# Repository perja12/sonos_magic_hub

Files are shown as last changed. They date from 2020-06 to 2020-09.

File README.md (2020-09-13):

# Sonos Magic Hub

_UPDATE 2020-09-13:_ This workaround isn't needed anymore! Go to "device connector" in the menus of the LG TV and setup a new soundbar. When you come to the manufacturer selection you won't see Sonos listed, but if you use the search box and search for Sonos it will show up (I'm pretty sure it wasn't there before!). Now you should be able to control the Sonos Playbar with the remote when the TV is on.

Next step is to open the Sonos app (S1), go to the settings for the Playbar and follow the instructions for setting up a remote ("Remote Control Setup"). And voilà: you can now control the Playbar with the MagicRemote with TV both on and off.

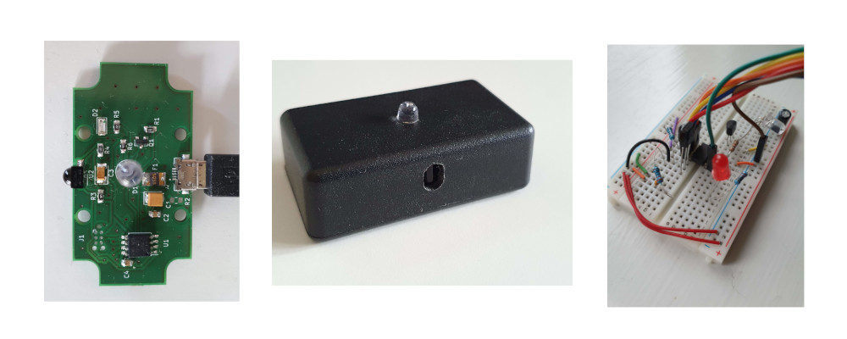
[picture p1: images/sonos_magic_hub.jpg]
Project pictures


This project contains firmware and hardware design files for using the LG Magic Remote that comes with LG OLED C9 TV with a Sonos Playbar. Sonos Playbar already has support for universal remotes, but the LG Magic Remote sends one set of codes when the TV is on and another set when the TV is off. So controlling the volume up, down and mute works fine when the TV is on, but not when it is off. It's not clear why LG has done it this way, but probably it is for controlling other LG devices.

Instead of waiting for LG to fix this I created a small circuit to translate the IR codes.

Note: there are various forum posts about the reverse problem for LG OLED CX. Apparently the Sonos Playbar can only be controlled by the LG remote when TV is off. This project doesn't solve that.

## How does it work?

This is straightforward: when a IR signal is received it will be converted to a code that the Sonos Playbar understands.

## List of IR codes

The table shows the IR codes sent by the remote when it is configured to send Philips RC6 codes as described here: https://support.sonos.com/s/article/3479?language=en

| Command | IR code (TV off) | IR code (TV on) |
|---|---|---|
| Volume up | NEC, 20DF40BF, 32 bits | RC6, 1010, 20 bits |
| Volume down | NEC, 20DFC03F, 32 bits | RC6, 1011, 20 bits |
| Mute | NEC, 0DF906F, 32 bits | RC6, 100D, 20 bits |

## How to build the firmware

Use the Arduino IDE and install the ATTinyCore (https://github.com/SpenceKonde/ATTinyCore). Do this from Boards Manager in the IDE. Select "ATtiny 25/45/85" under boards and clock to 8 MHz (internal). For uploading the firmware I have used USBasp with Tag-Connect, but you can you use any way you prefer. Remember to burn the bootloader before uploading the firmware.

## Various notes

* Use this at your own risk! In the firmware I included support for NEC repeat code that the remote sends if one of the buttons are held down. There is a limit of 5 repeats in a row to avoid ramping up the volume too fast.
* There is no USB enumeration and thereby it is not according to the USB specifications. Still I think it should work fine with most USB hosts.
* It was unclear if the shield of the USB connector should be connected to GND or not. That is why I included R2. I left it unpopulated.
* The fuse (F1) is probably not needed. Maybe it should have some TVS diodes instead to suppress ESD.
* The IR library is from https://gist.github.com/SeeJayDee/caa9b5cc29246df44e45b8e7d1b1cdc5

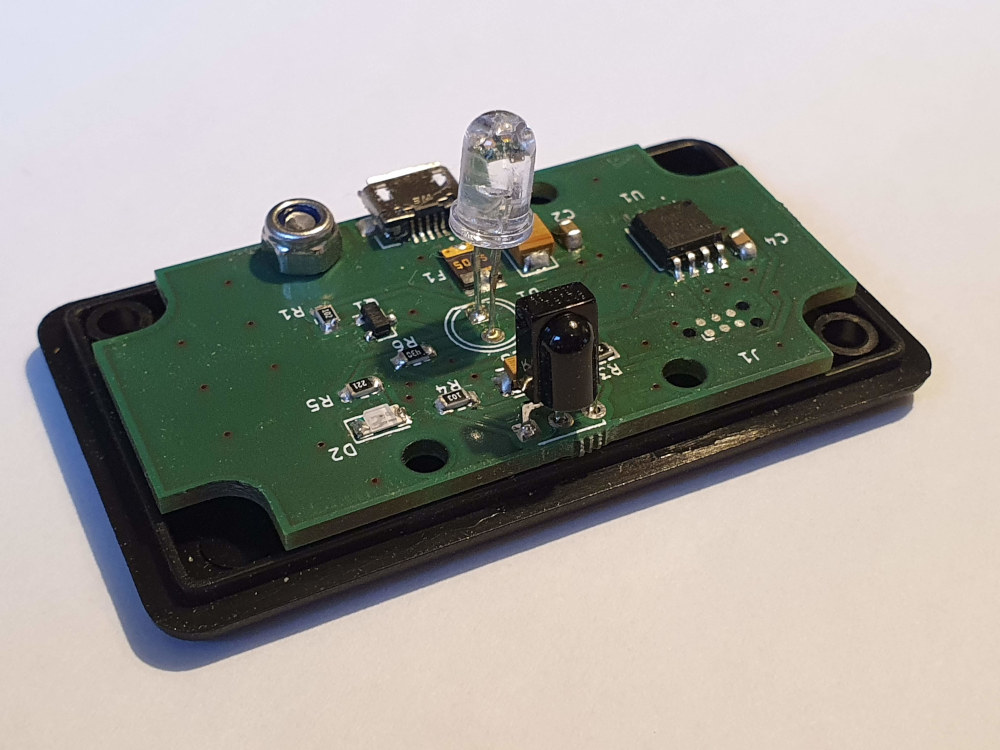
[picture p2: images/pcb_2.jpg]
PCB


## BOM

|Ref|Value |Footprint |
|---|---|---|
|C1 |10 uF |Capacitor_Tantalum_SMD:CP_EIA-3528-12_Kemet-T_Pad1.50x2.35mm_HandSolder |
|C2 |1 uF |Capacitor_SMD:C_0805_2012Metric_Pad1.15x1.40mm_HandSolder |
|C3 |0.1 uF |Capacitor_Tantalum_SMD:CP_EIA-3528-12_Kemet-T_Pad1.50x2.35mm_HandSolder |
|C4 |0.1 uF |Capacitor_SMD:C_0805_2012Metric_Pad1.15x1.40mm_HandSolder |
|D1 |LD271 |LED_THT:LED_D5.0mm_IRGrey |
|D2 |LED |LED_SMD:LED_1206_3216Metric |
|F1 |Polyfuse_Small|FUSM1812X02:FUSM1812X02 |
|J1 |AVR-ISP-6 |(No actual part) Connector:Tag-Connect_TC2030-IDC-NL_2x03_P1.27mm_Vertical|
|J2 |629105136821  |(Micro USB connector) WE_629105136821:WE_629105136821 |
|Q1 |MMBT3904 |Package_TO_SOT_SMD:SOT-23 |
|R1 |1K |Resistor_SMD:R_0805_2012Metric_Pad1.15x1.40mm_HandSolder |
|R2 |0 |Resistor_SMD:R_0805_2012Metric_Pad1.15x1.40mm_HandSolder |
|R3 |220 |Resistor_SMD:R_0805_2012Metric_Pad1.15x1.40mm_HandSolder |
|R4 |10K |Resistor_SMD:R_0805_2012Metric_Pad1.15x1.40mm_HandSolder |
|R5 |220 |Resistor_SMD:R_0805_2012Metric_Pad1.15x1.40mm_HandSolder |
|R6 |35 |Resistor_SMD:R_0805_2012Metric_Pad1.15x1.40mm_HandSolder |
|U1 |ATtiny85V-10SU|Package_SO:SOIJ-8_5.3x5.3mm_P1.27mm |
|U2 |TSOP38238 |OptoDevice:Vishay_MINICAST-3Pin |

The PCB fits inside the Hammond 1551H (http://www.hammondmfg.com/pdf/1551H.pdf).

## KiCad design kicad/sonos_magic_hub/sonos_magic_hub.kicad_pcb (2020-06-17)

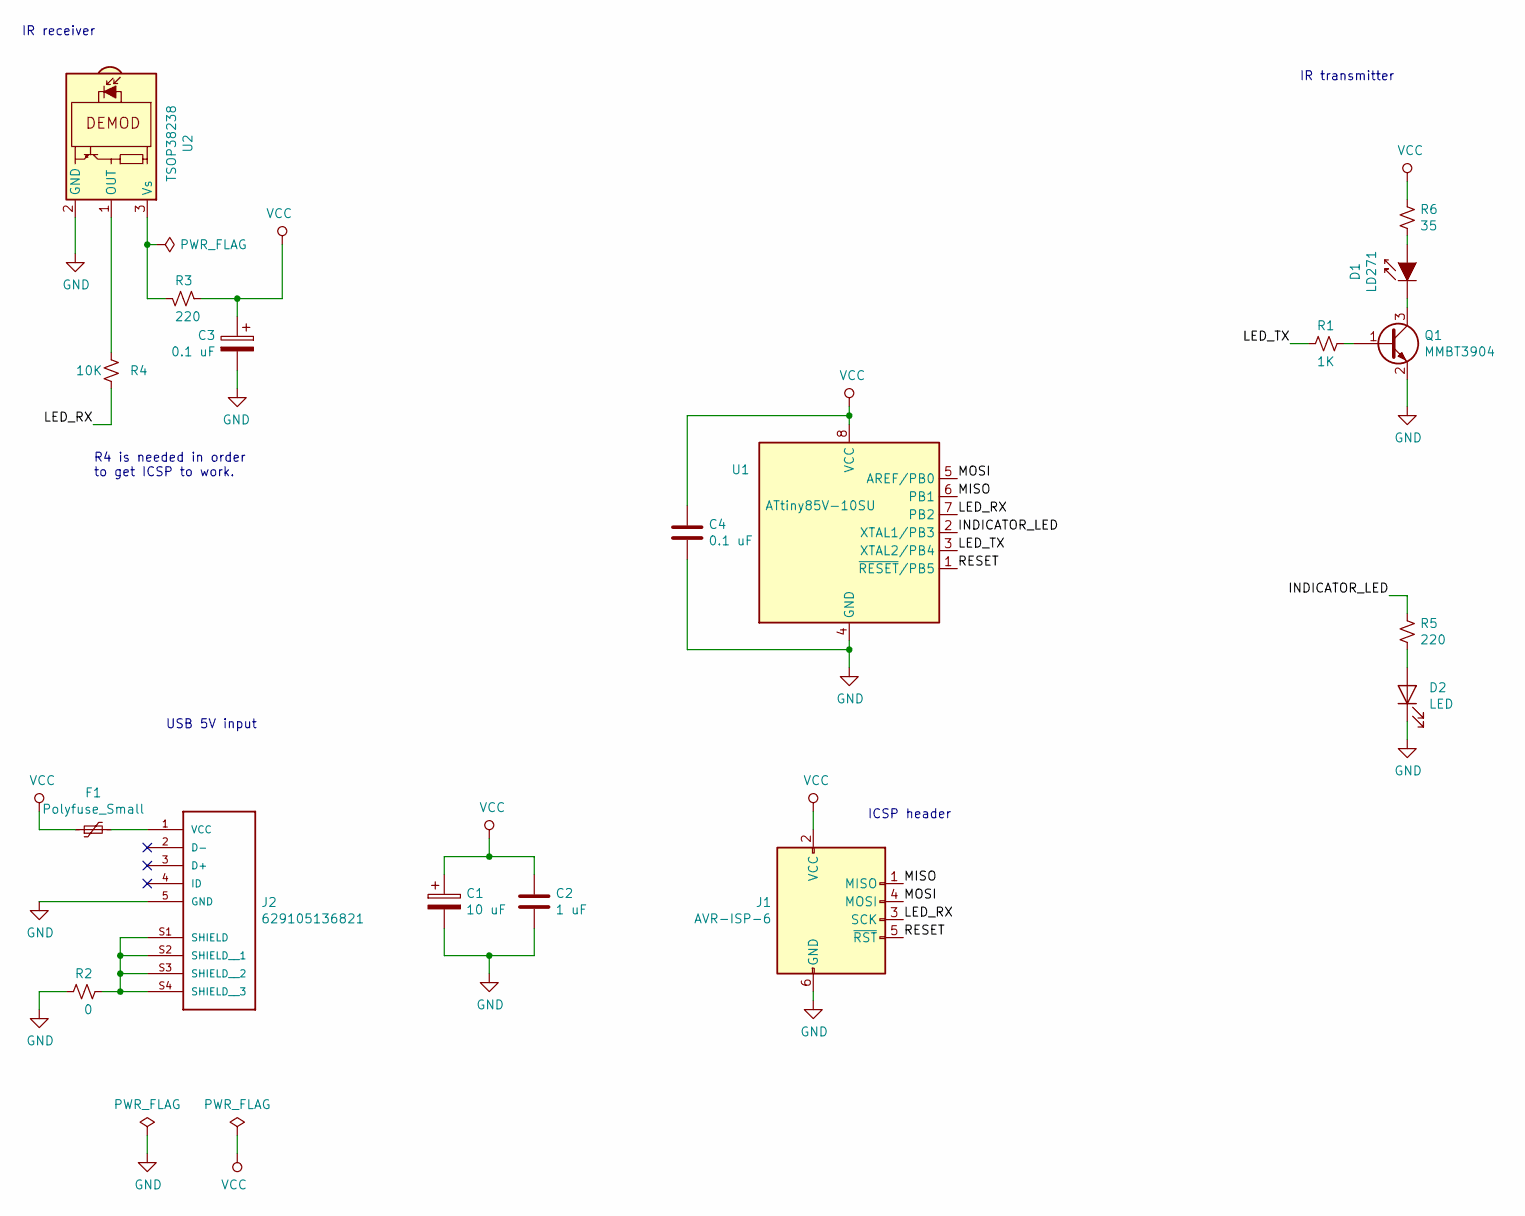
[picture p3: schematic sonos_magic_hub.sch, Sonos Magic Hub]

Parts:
C1: 10 uF; CP_EIA-3528-12_Kemet-T_Pad1.50x2.35mm_HandSolder
C2: 1 uF; C_0805_2012Metric_Pad1.15x1.40mm_HandSolder
C3: 0.1 uF; CP_EIA-3528-12_Kemet-T_Pad1.50x2.35mm_HandSolder
C4: 0.1 uF; C_0805_2012Metric_Pad1.15x1.40mm_HandSolder
D1: LD271; LED_D5.0mm_IRGrey
D2: LED; LED_1206_3216Metric
F1: Polyfuse_Small; FUSM1812X02
J1: AVR-ISP-6; Tag-Connect_TC2030-IDC-NL_2x03_P1.27mm_Vertical
J2: 629105136821; WE_629105136821
Q1: MMBT3904; SOT-23
R1: 1K; R_0805_2012Metric_Pad1.15x1.40mm_HandSolder
R2: 0; R_0805_2012Metric_Pad1.15x1.40mm_HandSolder
R3, R5: 220; R_0805_2012Metric_Pad1.15x1.40mm_HandSolder
R4: 10K; R_0805_2012Metric_Pad1.15x1.40mm_HandSolder
R6: 35; R_0805_2012Metric_Pad1.15x1.40mm_HandSolder
U1: ATtiny85V-10SU; SOIJ-8_5.3x5.3mm_P1.27mm
U2: TSOP38238; Vishay_MINICAST-3Pin

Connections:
/INDICATOR_LED: R5.1, U1.2 (XTAL1/PB3)
/LED_RX: J1.3 (SCK), R4.2, U1.7 (PB2)
/LED_TX: R1.1, U1.3 (XTAL2/PB4)
/MISO: J1.1 (MISO), U1.6 (PB1)
/MOSI: J1.4 (MOSI), U1.5 (AREF/PB0)
/RESET: J1.5 (~RST), U1.1 (~RESET~/PB5)
GND: C1.2, C2.2, C3.2, C4.2, D2.1 (K), J1.6 (GND), J2.5 (GND), Q1.2 (E), R2.1, U1.4 (GND), U2.2 (GND)
unnamed: D1.1 (K), Q1.3 (C)
unnamed: D1.2 (A), R6.2
unnamed: D2.2 (A), R5.2
unnamed: F1.2, J2.1 (VCC)
unnamed: J2.S1 (SHIELD), J2.S2 (SHIELD__1), J2.S3 (SHIELD__2), J2.S4 (SHIELD__3), R2.2
unnamed: Q1.1 (B), R1.2
unnamed: R3.2, U2.3 (Vs)
unnamed: R4.1, U2.1 (OUT)
VCC: C1.1, C2.1, C3.1, C4.1, F1.1, J1.2 (VCC), R3.1, R6.1, U1.8 (VCC)

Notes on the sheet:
ICSP header
IR receiver
IR transmitter
USB 5V input
R4 is needed in order to get ICSP to work.

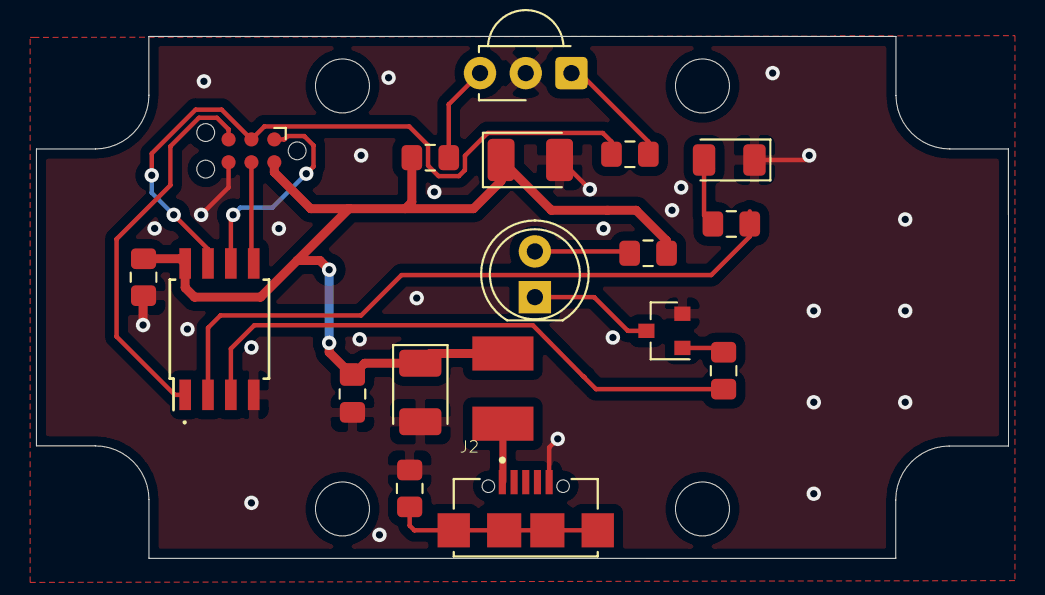
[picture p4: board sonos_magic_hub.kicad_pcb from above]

Board: 2 copper layers, 54.0 x 29.0 mm, 18 parts (0 on the bottom side), 16 nets.

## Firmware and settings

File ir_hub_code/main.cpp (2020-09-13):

#include <Arduino.h>
#include <avr/interrupt.h>
#include <avr/power.h>
#include <avr/sleep.h>
#include <util/delay.h>

#include "tiny_IRremote.h"

#define IR_RECV_PIN 2
#define INDICATOR_PIN 3

const uint32_t NEC_VOLUME_UP   = 0x20DF40BF;
const uint32_t NEC_VOLUME_DOWN = 0x20DFC03F;
const uint32_t NEC_VOLUME_MUTE = 0x20DF906F;
const uint32_t NEC_REPEAT      = 0xFFFFFFFF;

const uint16_t RC6_VOLUME_UP   = 0x1010;
const uint16_t RC6_VOLUME_DOWN = 0x1011;
const uint16_t RC6_VOLUME_MUTE = 0x100D;

// Limit the number of repeats to avoid damaging speaker element.
const uint8_t MAX_REPEATS = 5;

IRsend irsend;
IRrecv irrecv(IR_RECV_PIN);

uint32_t last_code = 0;
uint8_t num_repeats = 0;

EMPTY_INTERRUPT(PCINT0_vect);

void blink(uint8_t num) {
  for (uint8_t i = 0; i < num; i++) {
    PORTB |= (1 << INDICATOR_PIN);
    _delay_ms(20);
    PORTB &= ~(1 << INDICATOR_PIN);
    _delay_ms(20);
  }
}

void setup() {
  // The internal oscillator seems to be pretty accurate from factory for ATTiny85V.
  // Test sketch that generates 10 kHz PWM measures approx 10.07 kHz with
  // OSCCAL -= 1.
  OSCCAL -= 1;

  set_sleep_mode(SLEEP_MODE_IDLE);
  irrecv.enableIRIn();

  // Turn off ADC and USI to save power.
  ADCSRA &= ~ bit(ADEN);
  power_adc_disable();
  power_usi_disable();

  // Configure DDB0 and DDB1 as output to save power (unused).
  // In addition PB4 is configured by tiny_IRremote.
  DDRB = (1 << INDICATOR_PIN) | (1 << DDB0) | (1 << DDB1);

  PCMSK  |= _BV (PCINT2);  // enable pin change interrupt for PCINT2 pin (IR_RECV_PIN)
  GIFR   |= bit (PCIF);    // clear any outstanding interrupts
  GIMSK  |= bit (PCIE);    // enable pin change interrupts

  blink(3);
}

void send(uint32_t code) {
  irsend.sendRC6(code, 20);
  last_code = code;
  num_repeats = 0;
}

void send_last_code() {
  if (num_repeats < MAX_REPEATS) {
    irsend.sendRC6(last_code, 20);
    num_repeats++;
    _delay_ms(50);
  }
}

void loop() {
  decode_results results;
  uint8_t found_code = 0;

  // The IR library uses timer1 to collect raw IR data.
  // This is done in chunks of 50 ms. Repeatedly check for
  // data until there is data to decode or there is a timeout.
  uint32_t decode_start = millis();
  while ((found_code = irrecv.decode(&results)) == 0) {
    if ((millis() - decode_start) > 100) {
      break;
    }
  }

  if (found_code) {
    if (results.decode_type == NEC) {
      blink(1);
      switch(results.value) {
        case NEC_VOLUME_UP: send(RC6_VOLUME_UP); break;
        case NEC_VOLUME_DOWN: send(RC6_VOLUME_DOWN); break;
        case NEC_VOLUME_MUTE: send(RC6_VOLUME_MUTE); break;
        case NEC_REPEAT: send_last_code(); break;
      }
    }
    irrecv.enableIRIn();
    irrecv.resume();
  }

  power_timer0_disable();
  power_timer1_disable();
  sleep_mode();
  power_timer0_enable();
  power_timer1_enable();
}

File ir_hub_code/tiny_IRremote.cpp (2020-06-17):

/*
 * tiny_IRremote
 * Version 0.2 July, 2016
 * Christian D'Abrera
 * Fixed what was originally rather broken code from http://www.gammon.com.au/Arduino/
 * ...itself based on work by Ken Shirriffr.
 *
 * This code was tested for both sending and receiving IR on an ATtiny85 DIP-8 chip.
 * IMPORTANT: IRsend only works from PB4 ("pin 4" according to Arduino). You will need to 
 * determine which physical pin this corresponds to for your chip, and connect your transmitter
 * LED there.
 *
 * Copyright 2009 Ken Shirriff
 * For details, see http://arcfn.com/2009/08/multi-protocol-infrared-remote-library.html
 *
 * Interrupt code based on NECIRrcv by Joe Knapp
 * http://www.arduino.cc/cgi-bin/yabb2/YaBB.pl?num=1210243556
 * Also influenced by http://zovirl.com/2008/11/12/building-a-universal-remote-with-an-arduino/
 */

#include "tiny_IRremote.h"
#include "tiny_IRremoteInt.h"

// Provides ISR
#include <avr/interrupt.h>

volatile irparams_t irparams;

// These versions of MATCH, MATCH_MARK, and MATCH_SPACE are only for debugging.
// To use them, set DEBUG in tiny_IRremoteInt.h
// Normally macros are used for efficiency
#ifdef DEBUG
#error debug enabled
int MATCH(int measured, int desired) {
  Serial.print("Testing: ");
  Serial.print(TICKS_LOW(desired), DEC);
  Serial.print(" <= ");
  Serial.print(measured, DEC);
  Serial.print(" <= ");
  Serial.println(TICKS_HIGH(desired), DEC);
  return measured >= TICKS_LOW(desired) && measured <= TICKS_HIGH(desired);
}

int MATCH_MARK(int measured_ticks, int desired_us) {
  Serial.print("Testing mark ");
  Serial.print(measured_ticks * USECPERTICK, DEC);
  Serial.print(" vs ");
  Serial.print(desired_us, DEC);
  Serial.print(": ");
  Serial.print(TICKS_LOW(desired_us + MARK_EXCESS), DEC);
  Serial.print(" <= ");
  Serial.print(measured_ticks, DEC);
  Serial.print(" <= ");
  Serial.println(TICKS_HIGH(desired_us + MARK_EXCESS), DEC);
  return measured_ticks >= TICKS_LOW(desired_us + MARK_EXCESS) && measured_ticks <= TICKS_HIGH(desired_us + MARK_EXCESS);
}

int MATCH_SPACE(int measured_ticks, int desired_us) {
  Serial.print("Testing space ");
  Serial.print(measured_ticks * USECPERTICK, DEC);
  Serial.print(" vs ");
  Serial.print(desired_us, DEC);
  Serial.print(": ");
  Serial.print(TICKS_LOW(desired_us - MARK_EXCESS), DEC);
  Serial.print(" <= ");
  Serial.print(measured_ticks, DEC);
  Serial.print(" <= ");
  Serial.println(TICKS_HIGH(desired_us - MARK_EXCESS), DEC);
  return measured_ticks >= TICKS_LOW(desired_us - MARK_EXCESS) && measured_ticks <= TICKS_HIGH(desired_us - MARK_EXCESS);
}
#endif

void IRsend::sendNEC(unsigned long data, int nbits)
{
  enableIROut(38);
  mark(NEC_HDR_MARK);
  space(NEC_HDR_SPACE);
  for (int i = 0; i < nbits; i++) {
    if (data & TOPBIT) {
      mark(NEC_BIT_MARK);
      space(NEC_ONE_SPACE);
    } 
    else {
      mark(NEC_BIT_MARK);
      space(NEC_ZERO_SPACE);
    }
    data <<= 1;
  }
  mark(NEC_BIT_MARK);
  space(0);
}

void IRsend::sendSony(unsigned long data, int nbits) {
  enableIROut(40);
  mark(SONY_HDR_MARK);
  space(SONY_HDR_SPACE);
  data = data << (32 - nbits);
  for (int i = 0; i < nbits; i++) {
    if (data & TOPBIT) {
      mark(SONY_ONE_MARK);
      space(SONY_HDR_SPACE);
    } 
    else {
      mark(SONY_ZERO_MARK);
      space(SONY_HDR_SPACE);
    }
    data <<= 1;
  }
}

void IRsend::sendRaw(unsigned int buf[], int len, int hz)
{
  enableIROut(hz);
  for (int i = 0; i < len; i++) {
    if (i & 1) {
      space(buf[i]);
    } 
    else {
      mark(buf[i]);
    }
  }
  space(0); // Just to be sure
}

// Note: first bit must be a one (start bit)
void IRsend::sendRC5(unsigned long data, int nbits)
{
  enableIROut(36);
  data = data << (32 - nbits);
  mark(RC5_T1); // First start bit
  space(RC5_T1); // Second start bit
  mark(RC5_T1); // Second start bit
  for (int i = 0; i < nbits; i++) {
    if (data & TOPBIT) {
      space(RC5_T1); // 1 is space, then mark
      mark(RC5_T1);
    } 
    else {
      mark(RC5_T1);
      space(RC5_T1);
    }
    data <<= 1;
  }
  space(0); // Turn off at end
}

// Caller needs to take care of flipping the toggle bit
void IRsend::sendRC6(unsigned long data, int nbits)
{
  enableIROut(36);
  data = data << (32 - nbits);
  mark(RC6_HDR_MARK);
  space(RC6_HDR_SPACE);
  mark(RC6_T1); // start bit
  space(RC6_T1);
  int t;
  for (int i = 0; i < nbits; i++) {
    if (i == 3) {
      // double-wide trailer bit
      t = 2 * RC6_T1;
    } 
    else {
      t = RC6_T1;
    }
    if (data & TOPBIT) {
      mark(t);
      space(t);
    } 
    else {
      space(t);
      mark(t);
    }

    data <<= 1;
  }
  space(0); // Turn off at end
}

void IRsend::mark(int time) {
  // Sends an IR mark for the specified number of microseconds.
  // The mark output is modulated at the PWM frequency.
  GTCCR |= _BV(COM1B1); // Enable pin 3 PWM output (PB4 - Arduino D4)
  delayMicroseconds(time);
}

/* Leave pin off for time (given in microseconds) */
void IRsend::space(int time) {
  // Sends an IR space for the specified number of microseconds.
  // A space is no output, so the PWM output is disabled.
  GTCCR &= ~(_BV(COM1B1)); // Disable pin 3 PWM output (PB4 - Arduino D4)
  delayMicroseconds(time);
}

void IRsend::enableIROut(int khz) {
  // Enables IR output.  The khz value controls the modulation frequency in kilohertz.
  // The IR output will be on pin 3 (PB4 - Arduino D4) (OC1B).
  // This routine is designed for 36-40KHz; if you use it for other values, it's up to you
  // to make sure it gives reasonable results.  (Watch out for overflow / underflow / rounding.)
  // TIMER1 is used in fast PWM mode, with OCR1Ccontrolling the frequency and OCR1B
  // controlling the duty cycle.
  // There is no prescaling, so the output frequency is 8MHz / (2 * OCR1C)
  // To turn the output on and off, we leave the PWM running, but connect and disconnect the output pin.
  // A few hours staring at the ATmega documentation and this will all make sense.
  // See my Secrets of Arduino PWM at http://arcfn.com/2009/07/secrets-of-arduino-pwm.html for details.

  
  // Disable the Timer1 Interrupt (which is used for receiving IR)
  TIMSK &= ~_BV(TOIE1); //Timer1 Overflow Interrupt

  
  pinMode(4, OUTPUT);  // (PB4 - Arduino D4 - physical pin 3)
  digitalWrite(4, LOW); // When not sending PWM, we want it low
  

  // CTC1 = 1: TOP value set to OCR1C
  // CS = 0001: No Prescaling
  TCCR1 = _BV(CTC1) | _BV(CS10);
  
  // PWM1B = 1: Enable PWM for OCR1B
  GTCCR = _BV(PWM1B);

  // The top value for the timer.  The modulation frequency will be SYSCLOCK / OCR1C.
  OCR1C = SYSCLOCK / khz / 1000;
  OCR1B = OCR1C / 3; // 33% duty cycle

}

IRrecv::IRrecv(int recvpin)
{
  irparams.recvpin = recvpin;
}
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
